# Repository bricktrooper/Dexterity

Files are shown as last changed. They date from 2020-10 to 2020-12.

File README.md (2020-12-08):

# Dexterity

Dexterity is a wearable gesture recognition device which uses custom hardware, firmware, and software to measure hand movement and finger position via an array of specialized sensors.  This data can be interpreted in real time to identify hand gestures and execute corresponding actions on a computer system.  Dexterity is designed to be a scalable and can be used as a peripheral for any electronic device.  This makes it suitable for a variety of applications involving gesture recognition.

A common approach towards gesture recognition is to use computer vision and machine learning in order to decipher gestures through a video feed.  This can be a computationally intensive task, depending on the complexity of the algorithms and the hardware capabilities, which in turn increases latency and decreases throughput.

Dexterity tackles this issue by placing sensors directly on a wearable glove.  The sensors are continuously sampled by an onboard microcontroller, which transmits the readings to a host PC via a high-speed serial UART connection.  The stronger hardware of the host can then be used to run interpretation algorithms on the raw readings.  This avoids placing unnecessary computational stress on a low power device while providing a more accurate model of the hand compared to computer vision.

## Hardware

Dexterity's hardware consists of a glove equipped with 8 sensors and a microcontroller.  Each finger has an attached flex sensor, which changes resistance when the finger bends.  This allows the position of each finger to be read accurately.  Additionally, a 3-axis analogue accelerometer is placed on the top of the glove, which can be used to determine the movement and orientation of the hand.

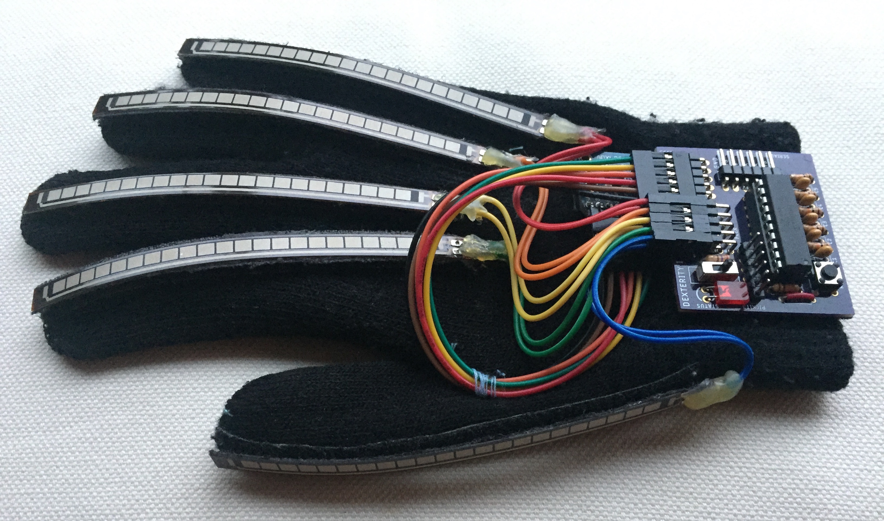
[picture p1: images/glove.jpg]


The device is powered by a custom circuit board with a Microchip PIC16F690 microcontroller.  This is an 8-bit low power computer that reads the flex sensors and accelerometer using its analogue-to-digital converter (ADC).

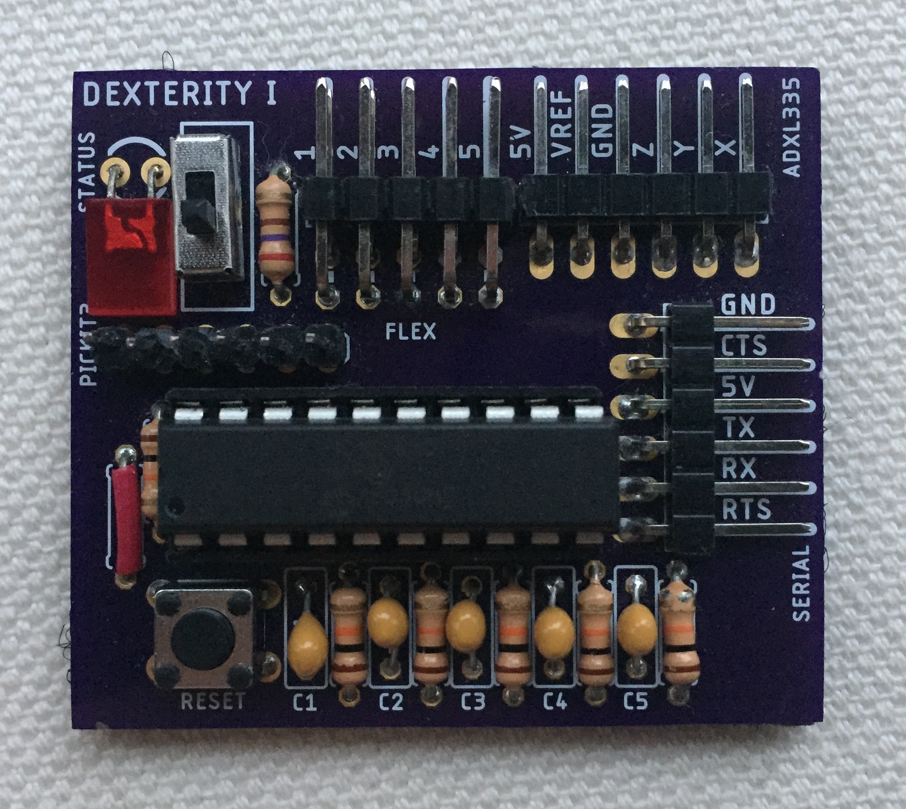
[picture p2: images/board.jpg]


The board requires a wired serial connection, which doubles as the 5V power supply.  If a wireless serial transmitter is used in the future, then a separate battery will be needed to power the board.  The accelerometer is an ADXL335 3-axis sensor module, composed of analogue output pins for the X, Y, and Z spatial directions.  Resistors were added for the flex sensors to produce a voltage divider sampling node, and 0.1uF filtering capacitors were added for noise reduction.  The board also contains an enable/disable button and a status LED.  Typical current draw ranges between 3.5mA and 4mA with a 5V supply.

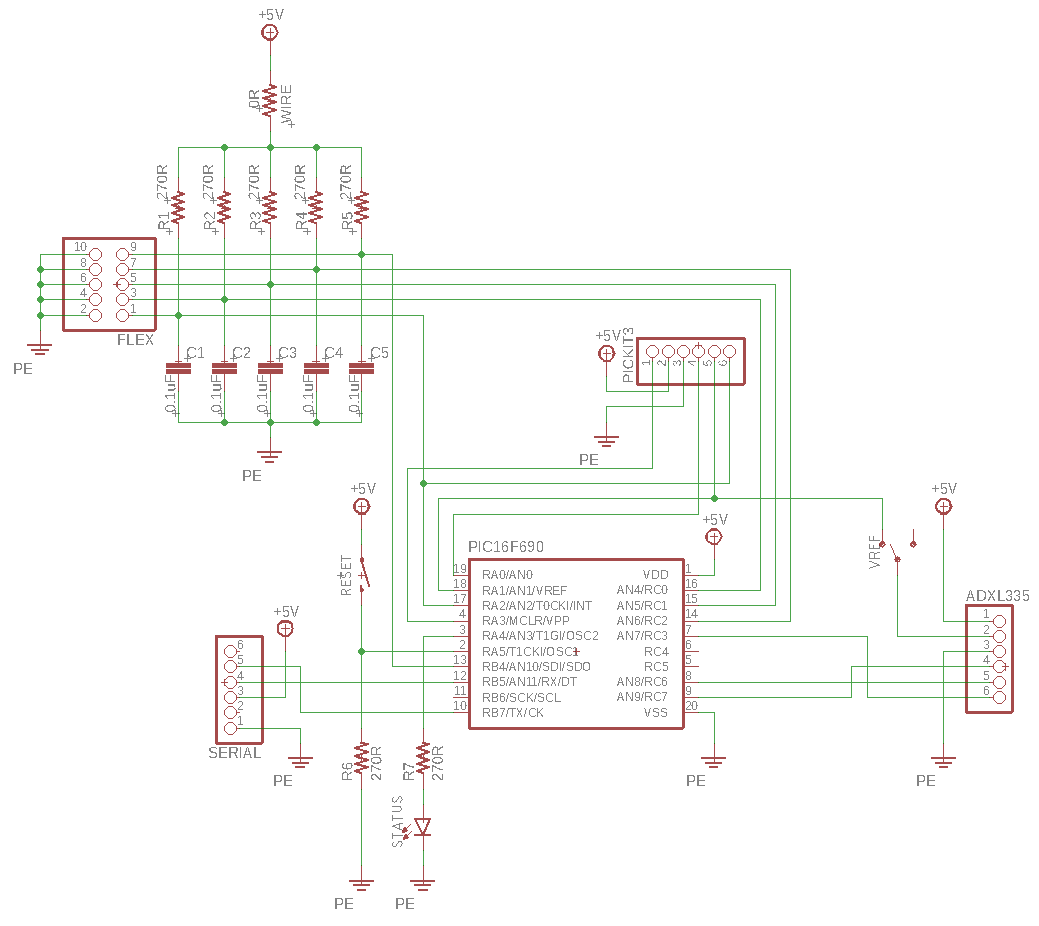
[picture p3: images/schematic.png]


Autodesk EAGLE was used to complete schematic entry and board layout.  These files can be found under the `hardware` directory.

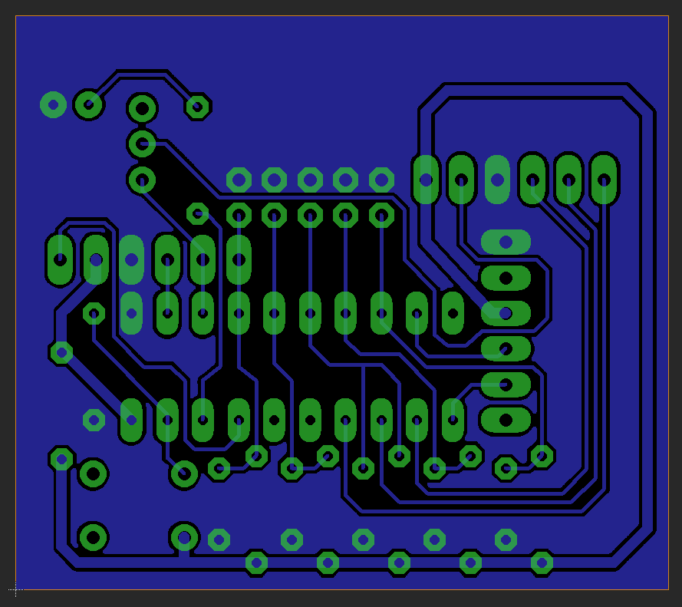
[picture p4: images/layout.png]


## Firmware

Custom firmware was developed to run on the PIC microcontroller.  This program runs forever as long as the board is powered.  The source code is located in the `firmware` directory.

The firmware reads the analogue voltages of each of the 8 sensors.  Each sensor is attached to an input pin, and the PIC will perform an ADC conversion on each of these analogue voltage inputs.  The microcontroller can also scale the readings between a certain range, which is useful for gesture interpretation.  If this is disabled, then the raw 10-bit ADC conversion values are returned instead.

The PIC transmits readings to a host device over a serial UART running at a baud rate of 115200 bits per second.  This results in less than 1ms of latency for data retrieval from the device.  The clock frequency of the PIC was increased to a maximum of 8MHz, which further reduces latency and increases the computational power.

The PIC can also send the current calibration settings to the host.  Similarly, the host can upload new calibration settings to the PIC.  Additionally, the host can tell the device to enable or disable scaling of the sensor readings.

The host and the device communicate using a set of short string messages.  The host will send messages to the PIC, and the firmware will continuously poll for a message.  If a valid message is received, the PIC will perform the requested action and return an ACK message signalling a success or an error.  In some cases, a data payload is sent instead of an ACK, such as a set of sensor readings.

## Software

The software is responsible for communicating with the device and interpreting the sensor readings to execute a specific function on the host computer.  The source code is located in the `software` directory of the repository.

The device must be connected to the computer via a serial-to-USB cable.  It is important that this cable is a **5V** variant and not a 3.3V variant, as a 5V supply is needed to power the device hardware.  The cable must have an embedded **FTDI FT232RL** chip, which allows the serial UART to appear as a USB device.  FTDI drivers may need to be installed to have this cable function correctly.

The software opens a serial port file descriptor and sets the attributes to match the settings used by the PIC.  The user can issue a variety of commands via the `dexterity` command line utility that the software compiles to.  While the main software is running, the program will continuously request sensor readings from the PIC.  Once the data arrives, it will be fed to an interpretation algorithm, which attempts to identify a hand gesture based on the average error and the tolerance.

If the readings match one of the valid gestures from the gesture list, then a corresponding action will be performed on the computer.  This might include playing/pausing a song, or moving and clicking the mouse.  There are different control modes as well, each with a different set of gestures.  The modes can be cycled through by flicking the thumb down and up again while keeping the other fingers straight and relaxed.  Pressing the push button on the board at any point will suspend the program.  The program can be resumed by pressing the button again.

The program will require a calibration file and a gestures file in order to function.  These can be found under the `config` directory, and can be easily modified for the application.

**NOTE:** The current software only works on Mac OS X, since it makes use of Apple's Quartz Event Services API.  This allows the program to inject events into HID stream in order to emulate mouse and keyboard events.  The software only supports the device as a computer peripheral, but the generality of the design can allow the user to control any electromechanical function by binding the trigger software appropriately.

## Compilation Instructions

### Build System

Dexterity uses a Makefile build system that compiles each source file separately and links the object files together at the end to produce a program binary.  The build system uses the `gcc` compiler to automatically generate file dependencies based on included header files.  These dependencies are stored in `*.d` dependency files.  The Makefiles use generalized pattern rules, which makes them highly scalable.  This allows additional source files to be added without major modifications to the Makefile.  All artifacts of the build system are placed in `bin` directories under the `software` and `firmware` source code folders.

### Firmware

The firmware is written in a dialect of C that is specific to the PIC microcontroller. The source code must be compiled using Microchip's XC8 compiler toolchain.  You will need to have these tools installed in order to build the firmware.  To compile the code, navigate to the `firmware` directory of the repository and execute the Makefile by typing `make`.  This will compile the code using the `xc8-cc` compiler and linker.  Each source file is compiled separately into object files with the `*.p1` extension, which are then linked into a single `*.hex` binary file and stored in the `bin` folder.  If you would like to view the PIC memory usage statistics, then add `MEMORY=show` as an argument when running `make`.  The firmware also has an alternate test program, which runs simple tests for each part of the firmware.  You can compile this version using the `test` target and by adding `TYPE=<TEST_NAME>`, where `TEST_NAME` can be any of the following:
* `INIT_TEST`
* `UART_TEST`
* `ADC_TEST`
* `ACCEL_TEST`
* `FLEX_TEST`
* `LED_TEST`
* `BUTTON_TEST`

To compile the test program:
```
make test TYPE=<TEST_NAME>
```
The test program can only be compiled from within the `firmware` directory.

### Software

The software is implemented in C with a few special functions written in Objective-C
The source code must be compiled using the Apple's version of the LLVM Clang compiler, which is able to link to the frameworks required for emulating the mouse and keyboard on Mac OS X.  Note that this will require installation of Apple's XCode command line tools, which include Clang and the Apple frameworks.  To compile the code, navigate to the `software` directory of the repository and execute the Makefile by typing `make`.  This will compile the code using the `clang` compiler and linker.  Each source file is compiled separately into object files with the `*.o` extension, which are then linked into an executable binary file and stored in the `bin` folder.  This `dexterity` binary file is executable from the command line.

### Top Level Build

Both the software and the firmware can be compiled at the same time by executing `make` from the top-level directory.  The top level Makefile will invoke the Makefiles from the `software` and `firmware` directories and place all generated artifacts in their respective `bin` folders, while also copying the binaries to a top level `artifacts` folder.

## Loading the Firmware

**IMPORTANT:** Before loading the firmware, slide the switch on the circuit board **away from the PIC** and **towards the edge of the board**.  This will disconnect the VREF input pin from the 3.3V pin on the ADXL335, putting the line in a high impedance state and eliminating any signalling conflicts.  Failing to do this will prevent the PICKit3 from interfacing with the PIC.

The firmware should be loaded onto the device using a PICKit3 serial in-circuit programmer.  Microchip's MPLAB IPE is required to connect to the PIC and load the `*.hex` firmware binary.

## Running the Program

**IMPORTANT:** Before running the program, ensure that the slide switch on the circuit board is moved **towards the PIC** and **away from the edge of the board**.  This attaches the VREF input of the PIC to the 3.3V pin on the ADXL335.  Failing to do this will result in the device producing an incorrect ADC reading for the acceleration axes.

The `dexterity` binary produced by compiling the software is an executable file.  You can run this from the command line:
```
./dexterity
```

This should bring up a list of available subcommands.  If you would like to use this command from anywhere, add the location of the binary to your PATH variable.

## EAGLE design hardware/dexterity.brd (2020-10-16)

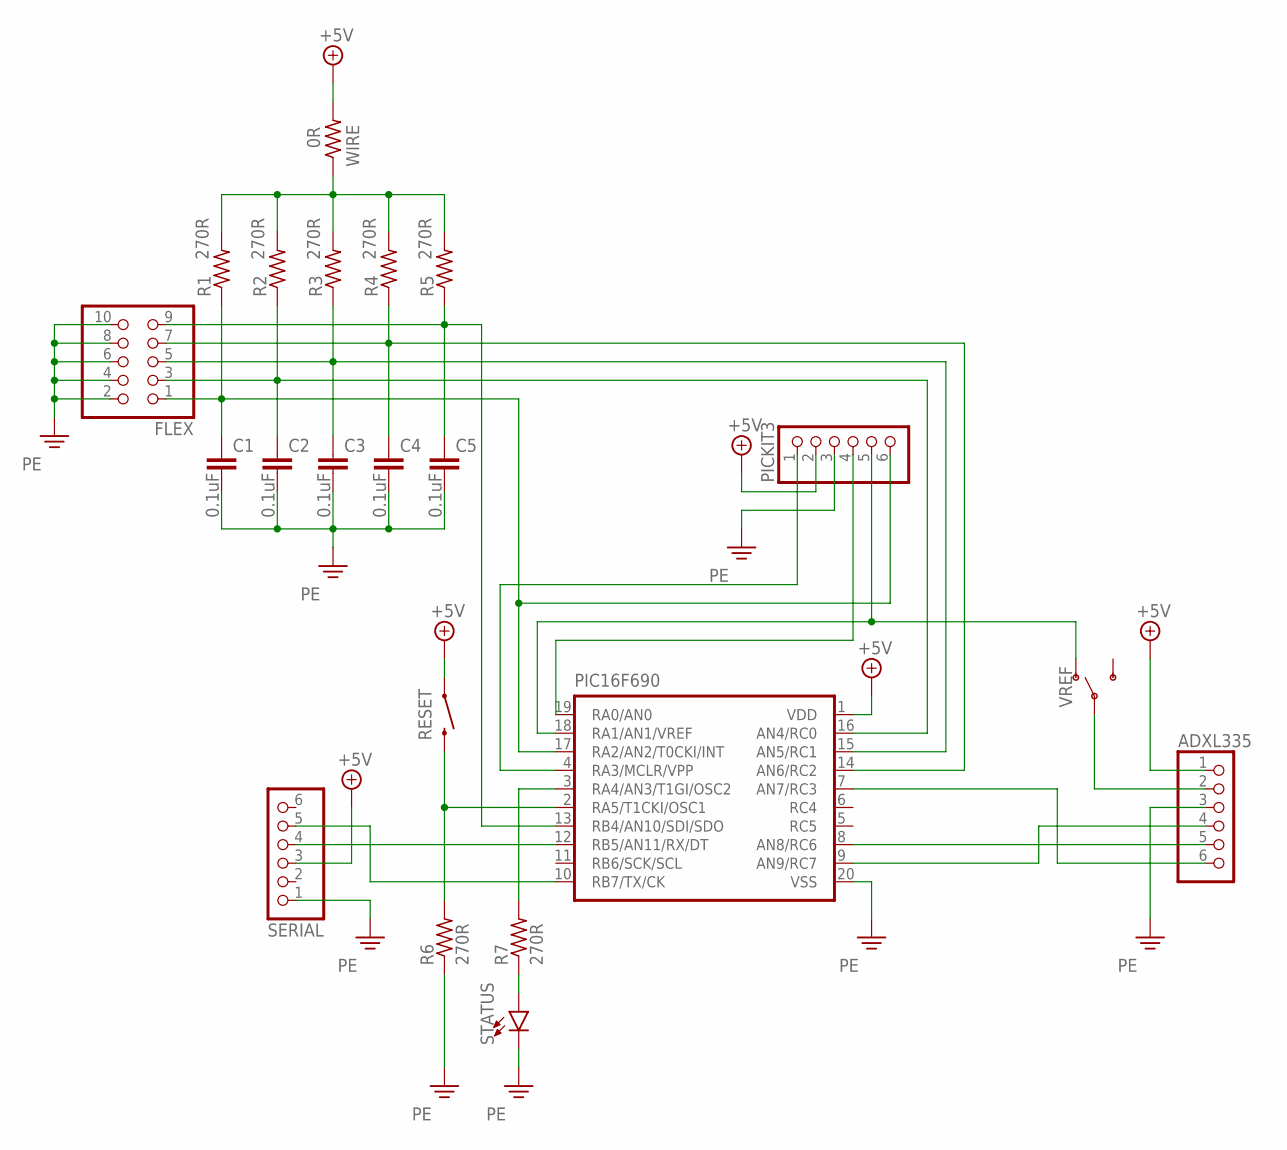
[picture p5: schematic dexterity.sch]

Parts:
ADXL335: PINHD-1X6/90; 1X06/90
C1, C2, C3, C4, C5: 0.1uF; C050-025X075
FLEX: PINHD-2X5/90; 2X05/90
PIC16F690: PIC16F6XX; DIL20
PICKIT3: PINHD-1X6; 1X06
R1, R2, R3, R4, R5, R6, R7: 270R; 0207/7
RESET: MOMENTARY-SWITCH-SPST-PTH-6.0MM; TACTILE_SWITCH_PTH_6.0MM
SERIAL: PINHD-1X6/90; 1X06/90
STATUS: LED3MM; LED_3MM
VREF: SWITCH-SPDT-PTH-11.6X4.0MM; SWITCH_SPDT_PTH_11.6X4.0MM
WIRE: 0R; 0207/7

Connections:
+5V: ADXL335.1, PIC16F690.1 (VDD), PICKIT3.2, R1.2, R2.2, R3.2, R4.2, R5.2, RESET.1, SERIAL.3, WIRE.1, WIRE.2
GND: ADXL335.3, C1.2, C2.2, C3.2, C4.2, C5.2, FLEX.2, FLEX.4, FLEX.6, FLEX.8, FLEX.10, PIC16F690.20 (VSS), PICKIT3.3, R6.1, SERIAL.1, STATUS.K (C)
unnamed: ADXL335.2, VREF.2
unnamed: PIC16F690.18 (RA1/AN1/VREF), PICKIT3.5, VREF.1 (O)
unnamed: PIC16F690.12 (RB5/AN11/RX/DT), SERIAL.4
unnamed: PIC16F690.10 (RB7/TX/CK), SERIAL.5
unnamed: PIC16F690.3 (RA4/AN3/T1GI/OSC2), R7.2
unnamed: ADXL335.5, PIC16F690.8 (AN8/RC6)
unnamed: ADXL335.6, PIC16F690.7 (AN7/RC3)
unnamed: PIC16F690.4 (RA3/MCLR/VPP), PICKIT3.1
unnamed: C2.1, FLEX.3, PIC16F690.16 (AN4/RC0), R2.1
unnamed: PIC16F690.19 (RA0/AN0), PICKIT3.4
unnamed: C1.1, FLEX.1, PIC16F690.17 (RA2/AN2/T0CKI/INT), PICKIT3.6, R1.1
unnamed: C3.1, FLEX.5, PIC16F690.15 (AN5/RC1), R3.1
unnamed: C4.1, FLEX.7, PIC16F690.14 (AN6/RC2), R4.1
unnamed: C5.1, FLEX.9, PIC16F690.13 (RB4/AN10/SDI/SDO), R5.1
unnamed: ADXL335.4, PIC16F690.9 (AN9/RC7)
unnamed: R7.1, STATUS.A
unnamed: PIC16F690.2 (RA5/T1CKI/OSC1), R6.2, RESET.3 (2)

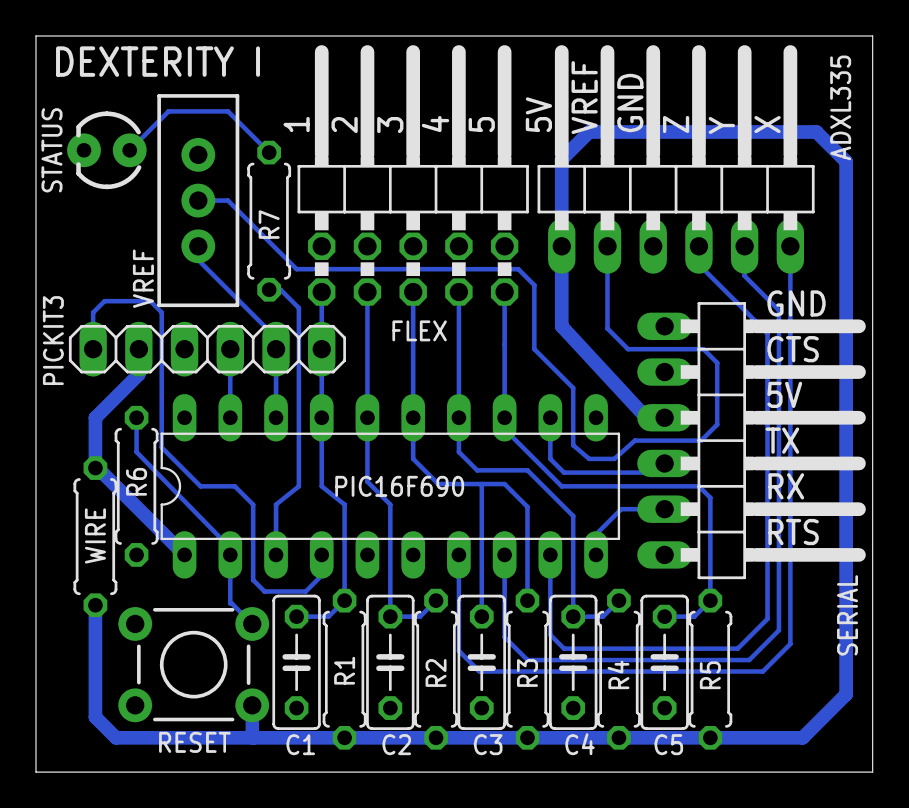
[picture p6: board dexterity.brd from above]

Board: 2 copper layers, 46.5 x 40.9 mm, 21 parts (0 on the bottom side), 19 nets.

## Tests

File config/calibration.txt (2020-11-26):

accel-range=100
flex-range=2
X      MIN=528 MAX=600 CENTRE=50
Y      MIN=487 MAX=603 CENTRE=0
Z      MIN=406 MAX=614 CENTRE=50
THUMB  MIN=560 MAX=726 CENTRE=0
INDEX  MIN=548 MAX=780 CENTRE=0
MIDDLE MIN=531 MAX=750 CENTRE=0
RING   MIN=524 MAX=763 CENTRE=0
PINKY  MIN=530 MAX=724 CENTRE=0

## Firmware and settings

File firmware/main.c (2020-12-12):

#include <xc.h>
#include <pic16f690.h>

#include <string.h>
#include <stdbool.h>

#include "dexterity.h"
#include "pins.h"
#include "utils.h"
#include "init.h"
#include "led.h"
#include "button.h"
#include "uart.h"
#include "adc.h"
#include "accel.h"
#include "flex.h"

void init(void);
int sample(Hand * hand);
void raw(void);
void scaled(void);
int calibrate(Calibration * calibration);
int settings(Calibration * calibration);

void main(void)
{
	init();
	led_off();

	Hand hand;
	Calibration calibration;
	Message message;

	while (1)
	{
		// operations that change the device state will require an ACK
		// operations that simply request data do not require a separate ACK
		message = uart_receive_message();

		switch (message)
		{
			case MESSAGE_SAMPLE:   // read the analogue sensors and transmit the results

				sample(&hand);
				uart_transmit(&hand, sizeof(Hand));
				break;

			case MESSAGE_RAW:   // use raw ADC readings

				raw();
				uart_transmit_message(MESSAGE_SUCCESS);
				break;

			case MESSAGE_SCALED:   // scale ADC readings using the calibration

				scaled();
				uart_transmit_message(MESSAGE_SUCCESS);
				break;

			case MESSAGE_UPLOAD:   // receive the calibration settings and apply them

				uart_transmit_message(MESSAGE_SUCCESS);   // handshake with the host

				if (uart_receive(&calibration, sizeof(Calibration)) != sizeof(Calibration))
				{
					uart_transmit_message(MESSAGE_ERROR);
					break;
				}

				calibrate(&calibration);                  // apply the calibration
				uart_transmit_message(MESSAGE_SUCCESS);   // send an ACK when finished
				break;

			case MESSAGE_DOWNLOAD:   // transmit the current calibration settings

				settings(&calibration);                             // copy the current calibration settings
				uart_transmit(&calibration, sizeof(Calibration));   // send the calibration back to the host
				break;

			case MESSAGE_UNKNOWN:   // respond with error if an unexpected or unknown message is received
			default:

				uart_transmit_message(MESSAGE_ERROR);
				break;
		}
	}
}

void init(void)
{
	init_hardware();
	led_init();
	button_init();
	uart_init();
	adc_init();
	accel_init();
	flex_init();
}

int sample(Hand * hand)
{
	if (hand == NULL)
	{
		return ERROR;
	}

	// ACCELEROMETER //

	adc_vref(VREF_EXTERNAL);

	hand->accel[X] = accel_read(X);
	hand->accel[Y] = accel_read(Y);
	hand->accel[Z] = accel_read(Z);

	// FLEX SENSORS //

	adc_vref(VREF_INTERNAL);

	hand->flex[THUMB] = flex_read(THUMB);
	hand->flex[INDEX] = flex_read(INDEX);
	hand->flex[MIDDLE] = flex_read(MIDDLE);
	hand->flex[RING] = flex_read(RING);
	hand->flex[PINKY] = flex_read(PINKY);

	// BUTTON STATE //

	hand->button = BUTTON;

	// LED STATE //

	hand->led = LED;

	return SUCCESS;
}

void raw(void)
{
	accel_mode(RAW);
	flex_mode(RAW);
}

void scaled(void)
{
	accel_mode(SCALED);
	flex_mode(SCALED);
}


int calibrate(Calibration * calibration)
{
	if (calibration == NULL)
	{
		return ERROR;
	}

	if (accel_calibrate(&calibration->accel) == ERROR ||
		flex_calibrate(&calibration->flex) == ERROR)
	{
		return ERROR;
	}

	return SUCCESS;
}

int settings(Calibration * calibration)
{
	if (calibration == NULL)
	{
		return ERROR;
	}

	if (accel_settings(&calibration->accel) == ERROR ||
		flex_settings(&calibration->flex) == ERROR)
	{
		return ERROR;
	}

	return SUCCESS;
}

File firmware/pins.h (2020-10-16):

#ifndef PINS_H
#define PINS_H

// STATUS LED //

#define LED        RA4
#define LED_TRIS   TRISA4

// RESET BUTTON //

#define BUTTON        RA5
#define BUTTON_TRIS   TRISA5

// ACCELEROMETER //

#define X_TRIS   TRISC3
#define Y_TRIS   TRISC6
#define Z_TRIS   TRISC7

#define X_ANSEL   ANS7
#define Y_ANSEL   ANS8
#define Z_ANSEL   ANS9

#define X_CHANNEL   7
#define Y_CHANNEL   8
#define Z_CHANNEL   9

// FLEX SENSORS //

#define F1_TRIS    TRISA2
#define F2_TRIS    TRISC0
#define F3_TRIS    TRISC1
#define F4_TRIS    TRISC2
#define F5_TRIS    TRISB4

#define F1_ANSEL   ANS2
#define F2_ANSEL   ANS4
#define F3_ANSEL   ANS5
#define F4_ANSEL   ANS6
#define F5_ANSEL   ANS10

#define F1_CHANNEL   2
#define F2_CHANNEL   4
#define F3_CHANNEL   5
#define F4_CHANNEL   6
#define F5_CHANNEL   10

#endif /* PINS_H */

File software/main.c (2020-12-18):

#include <stdio.h>
#include <stdlib.h>
#include <libgen.h>

#include "dexterity.h"
#include "log.h"
#include "utils.h"
#include "command.h"

#define ARGV_MIN          1   // no subcommand
#define ARGV_MAX          4   // subcommand + arguments
#define ARGV_PROGRAM      0
#define ARGV_SUBCOMMAND   1
#define ARGV_ARGUMENTS    2

int main(int argc, char ** argv)
{
	// LOGGING SETTINGS //

	log_suppress(LOG_ERROR, false);
	log_suppress(LOG_WARNING, false);
	log_suppress(LOG_SUCCESS, false);
	log_suppress(LOG_INFO, false);
	log_suppress(LOG_DEBUG, true);

	log_trace(false);   // don't print the source of log messages

	// PARSE ARGUMENTS //

	if (argc < ARGV_MIN)
	{
		log(LOG_ERROR, "Insufficient arguments\n");
		print_usage(COMMAND_DEXTERITY, false);
		return ERROR;
	}

	if (argc > ARGV_MAX)
	{
		log(LOG_ERROR, "Too many arguments\n");
		print_usage(COMMAND_DEXTERITY, false);
		return ERROR;
	}

	if (argv == NULL)
	{
		log(LOG_ERROR, "Invalid argument vector\n");
		return ERROR;
	}

	char * subcommand = NULL;
	char ** arguments = NULL;
	int count = 0;

	if (argc > 1)
	{
		subcommand = argv[ARGV_SUBCOMMAND];
	}

	if (argc > 2)
	{
		count = argc - 2;
		arguments = &argv[ARGV_ARGUMENTS];
	}

	// RUN DEXTERITY //

	return dexterity(subcommand, arguments, count);
}

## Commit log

2020-09-21 firmware: Add basic init code for PIC16F690
    Basic initialization code for
    PIC operation. Configures the
    following features of the device:
    - Digital I/O
    - Analogue I/O
    - Internal Oscillator 4MHz (~3.6864MHz)
    - Initialization of GPIO PORTs
    A startup indication will be shown
    on PORTC is if the PIC test board is
    being used.
    [init.c]
2020-09-21 firmware: Create test file to run init code
    test.c will run the basic init code
    on the PIC. If the PIC test board
    is being used, the PORTC LEDs will
    light up.
2020-10-16 build: Add Makefile and guards for test board code
    Create a Makefile for building an init test
    program. If the PIC test board setting is
    used, the PORTC LEDs will flash and the
    buttons (RA4 and RA5) will be set as inputs.
    Also added init/out directory to .gitignore
2020-10-16 firmware: Add basic init code for testing
    This is later replaced by the init module
    [init.c]
2020-10-16 firmware: Add Makefile and test code file
    test.c will be used to test the UART code.
2020-10-16 firmware: Implement UART send function to output data serially
    This can be used to output to a console that
    operates at the same baud rate (9600).
2020-10-16 firmware: Implement UART receive functionality
    The PIC will read bytes until a null
    terminator, newline, or carriage return
    is received. It will then append a null
    terminator to the recieved data.
2020-10-16 firmware: Add error checking to UART functions
    [uart.c]
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2020-10-16 firmware: Remove init code from UART
    The init.c code is just a generic
    setup for the PIC and will appear
    instead in a seperate init folder.
    This allows multiple modules to
    access the init code in their
    individual test programs.
2020-10-16 firmware: ignore UART out folder
    The out directory just holds
    the build artifacts and does
    not need to be tracked.
2020-10-16 build: Update Makefile to use init module
    the UART test.c should use the init module
    instead of the old local init code.
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2020-10-16 firmware: Add buffer size to TX function
    Specify the size of the data buffer
    that is to be transmitted on the TX
    line. This is safer and more secure
    then transmitting until a newline or
    null terminator, which will be handled
    in the serial module's print functions.
2020-10-16 firmware: Create UART print functions
    Created printing functions for debugging
    and system console logging. These were
    implemented using the built-in putch()
    association, which adapts printf() to
    output to the UART instead of stdout.
    Functions currently available:
    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
2020-10-16 firmware: Add test code for Serial O/I
    Currently only tests printing over UART.
2020-10-16 firmware: Implement serial read function
    Add function to read input from UART
    into a buffer.
2020-10-16 firmware: Fix TRISB comment
    RB4 was marked as N/C.
    [init.c]
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2020-10-16 firmware: Implement ADC module functionality
    Added the following functions for operation
    of the ADC module:
    - adc_init()
    - adc_run()
    - adc_set_channel()
    - adc_read()
2020-10-16 firmware: Create test program for ADC
    Tests ADC readings from RB4 (AN10)
    and prints out the reading using
    functions from the serial module.
2020-10-16 firmware: Tune internal oscillator for new PICs
    When transistioning to breadboard development
    a brand new PIC16F690 was used. In order for
    the UART to correctly function, the internal
    oscillator needs to be tuned down to its
    minimum frequency. However, the UART on the
    original test board PIC functions correctly
    at the factory-calibrated default tuning level.
    Create preprocessor wrappings to deal with
    this difference. The cause of this may be
    investigated later, however the final product
    will use the new chips.
    [init.c, uart.c]
2020-10-16 firmware: Add LED status indicator on RC5
    This functions like the PORTC startup
    indicator from the PIC test board.
2020-10-16 hardware: Create first version of PCB
    Board was designed in EAGLE based on a schematic of the breadboard
    layout. The board will have the following features:
    - status LED
    - flex sensor angled DIP
    - accelerometer angled SIP
    - UART serial angled SIP
    - PICKit3 programmer SIP
    - PIC16F690 microcontroller
    - reset button with pull down resistor
    - slide switch for setting VREF to high-Z (used when programming PIC)
    - flex sensor pull up resistors
    - flex sensor filtering capacitors
    [dexterity.brd, dexterity.sch]
2020-10-16 firmware: Define min and max ADC readings
    Minimum ADC reading = 0
    Maximum ADC reading = 1023
2020-10-16 firmware: Read ADXL335 values using ADC
    The values will be scaled so that maximum acceleration is +100 and
    minimum acceleration is -100. Since the ADXL335 uses 3.3V as reference,
    the VREF for the ADC will be set to the 3.3V external line. This must
    be manually set before reading accelerometer readings.
2020-10-16 firmware: Read flex sensors using ADC
    The flex sensor values were scaled to the 0 <-> 100 range.
    This should be further calibrated when the flex sensors are on the
    glove. The addition of filtering capacitors will also change the
    calibration settings.
    [flex.c]
2020-10-16 firmware: Move all PIC code to firmware folder
    This will keep the repo more organized given that there will be
    different code for the drivers and user application.
2020-10-16 hardware: Rename EAGLE folder to 'pcb'
    This folder now has a special .gitignore to ignore backups for
    schematics and layouts that are automatically generated by EAGLE.
    [dexterity.brd, dexterity.sch]
2020-10-16 build: Add rule for building test firmware
    The regular firmware can be built using 'make dexterity' or simply
    'make'. This will compile the firmware using dexterity.c as the main
    program. To build the test firmware using test.c as the main program,
    run 'make test TYPE=<test_type>', where 'test_type' is the defined macro
    in test.c that specifies which test function to run.
    This eliminates the need to edit the source code of test.c in order to
    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
2020-10-16 firmware: Create pins.h containing pinout constants
    This file is used to store macros that are aliased with the pin names
    and analogue channels for the various peripherals on the board. This
    includes the accelerometer, flex sensors, LED, and button.
    [accel.c, flex.c, init.c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]
2020-10-16 firmware: Update test.c to work with Dexterity I board
    Updated the LED pins to work with init_test().
    Also removed the hardcoded macro at the top to work with the new build
    system that allows specification of the test type from the command line.
2020-10-16 hardware: Rename 'pcb' folder to 'hardware'
    [dexterity.brd, dexterity.sch]
2020-10-16 firmware: Added code for controlling status LED
    This new module allows the user to turn the LED on or off, as well as
    link the LED at a certain speed. This LED will be useful as a visual
    indicator of activity on the board.
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2020-10-16 firmware: Improve scaling and remove floating point operations
    Doing floating point operations on the PIC is much slower than integer
    operations and it takes up too much program space. The scaling has been
    optimized to use only integer arithmetic.
    Also added enums for organizing accelerometer and flex sensor settings
    and data.
    [accel.c, flex.c, test.c]
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2020-10-16 firmware: Fix pin assignments
    [pins.h]
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2020-10-16 software: Develop serial I/O module
    This code will be used to manage the UNIX serial port.
    It is capable of reading and writing data to and from the device.
    Note that the transmission has delays inserted between each byte,
    which avoids overrunning the PIC's RX buffer.
2020-10-16 firmware: Check for RX buffer overrun
    If data comes in too fast it will overrun the RX buffer
    and lock the receiver. Check for this while looping in
    uart_receive() and reset the receiver if necessary.
    [uart.c]
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2020-10-16 common: Use standard size for transmitted data fields
    On the PIC an int is a 16b number, while on the host it
    is usually a 32b number. These sizes must be consistent
    in order to avoid data misinterpretation.
    Use the int16_t type to represent all integer data that
    will be transmitted and received over UART between the
    device and the host.
    [accel.c, adc.c, dexterity.h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]
2020-10-16 common: Move enums for accel and flex into universal header
    [dexterity.h]
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2020-10-16 common: Move common source code files into a central folder
    The Makefile include paths had to be tweaked to accommodate this.
    Also added a single file for messages, which avoids having multiple
    definitions in different files. All files will link to this one.
    [dexterity.h, test.c]
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2020-10-16 common: Add strings for accel and flex in common
    This is just for printing aesthetics.
    [dexterity.h]
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2020-10-16 common: Fix size of shared data structures and enums
    The sizeof operator was not being used correctly.
    Use macro constants instead and enforce these sizes
    on the string arrays in dexterity.c
    [dexterity.h]
2020-10-16 common: Fix analogue parameter ordering
    Make it consistent with the PIC code ordering
    [dexterity.h]
2020-10-16 software: Add interactive calibration
    This allows the user to calibrate the analogue sensor limits
    using the push button. These values can be sent to the device
    to correct the output scaling.
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2020-10-16 firmware: Transmit current calibration upon request
    The device will transfer its current calibration values
    when the host requests them via the correct message.
    [main.c]
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2020-10-16 build: Prevent Makefile from regenerating dependencies during a clean
    We don't need to generate dependencies when running 'make clean'
    [adc.c]
2020-10-16 build: Fix dependency generation to track headers
    The header files were not being tracked by make
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2020-10-16 common: Put enum lengths inside enumeration list
    The number of enumerations for each type of enum were originally defined
    as macros. This may have been causing warnings, especially if enum
    numbering is different between gcc and xc8. By making the last enum
    member the length of the enum, we can always ensure that the correct
    length is used across the firmware and the software.
    [dexterity.h]
2020-10-16 build: Fix individual target recipes
    The artifacts should be copied to the top level even when individual
    recipes are run. Also fixed the printing to work with the -j option.
2020-10-17 common: Remove error code from scaling function
    This function returns the scaled value. We cannot return an error code
    as the scaled value may be the same as the error code. If there is an
    error, simply return the sensor reading unchanged.
2020-10-17 firmware: Implement retrieval of calibration settings
    Added a new function for flex and accel that will fetch the current
    calibration settings so that they can be send back to the host PC.
    [accel.c, flex.c, main.c]
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2020-10-17 software: Remove debug print in sampling function
    This is unnecessary overhead, even if suppressed.
    This function must have minimal latency, so this
    printing can be done manually elsewhere. The sample
    subcommand will replace this functionality anyway.
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2020-10-24 firmware: Increase PIC internal oscillator frequency to 8MHz
    This effectively doubles the device operation speed from the original
    4MHz frequency, resulting in faster computation and sampling of sensors.
    This will also result in increased thermals for the chip.
    [init.c]
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2020-10-24 software: Prevent cursor from moving beyond the screen limits
    Quartz already prevents this but the mouse coordinates can still become
    invalid. Currently this uses the hardcoded limits of a 1920x1080 screen
    but these should be set dynamically at runtime.
2020-10-27 software: Check explicitly for error code in function return codes
    [main.c]
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2020-10-28 common: Use void pointers for passing buffers
    This avoids ugly casting when calling the function.
    casts to char pointer handles are done withing the
    functions themselves.
    [main.c, uart.c]
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2020-10-28 software: Purge serial port before every write
    serial_purge() was inserted directly into serial_write().
    This avoids the need to manually call it before every write.
    The logic behind purging is to clear an pending data that may be
    stuck in the TX buffer. This ensures that the new data is transmitted
    as expected without any additional remnants from previous transfers.
    The RX buffer is never purged before data is read from the serial port,
    as read() may block, so we don't want to lose data if the entire
    transmission is still coming in. write() will simply dump the data in
    the TX buffer and return, so we don't know for sure when it has been
    transmitted. This is the reason we use serial_purg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
2020-10-29 software: Fix byte counter print for serial error message
2020-10-31 common: Restructure calibration struct to use 2D array
    This allows us to iterate over the analogue calibration parameters
    easily, similar to how the acceleration and flex sensor readings can
    be iterated over using their enums.
    [dexterity.h]
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2020-10-31 firmware: ACK with error if an unexpected or unknown message is received
    [main.c]
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2020-11-02 software: Fix calibration export success message
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2020-11-02 software: Fix segfault in phase label mismatch printing
2020-11-02 common: Fix indentation for broken lines
    Tabs should only be used for indenting different scopes and levels of
    code. For formatting code beyond this point use spaces to ensure that
    the code lines up correctly.
    [accel.c, flex.c]
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2020-11-08 software: Use a separate phase for each gesture
    This avoid confusion when switching between different gestures.
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2020-12-02 software: Control volume using gestures
    Volume is a separate mode of operation. If all the hand fingers are
    clasped, then the volume can be controlled by tiling left and right.
    Also improved the gesture for overview so that it does not get mistaken
    with a recovery from a drag gesture.
    [dexterity.h]
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2020-12-03 software: Re-download calibration after uploading to verify data
    There is the possibility that noise could corrupt either the upload or
    the download, but it seems to be rare. In any case, if there is a
    suspicion on data corruption during an upload, the user will be notified.
2020-12-03 common: Change WARNING return code from 1 to -2
    A UNIX signals might have a value of 1 and this should not be confused
    with an return code of WARNING. All three return codes (ERROR, SUCCESS,
    and WARNING) will be <= 0 to avoid conflicting with UNIX signal values
    which are > 0 (these signals may interrupt the program via end()).
    [dexterity.h, main.c]
2020-12-04 common: Shorten max message
    The size was much larger than the possible max size.
    [dexterity.h]
2020-12-05 software: Create help and usage messages
    These can be triggered using the '--help' command line argument.
    Each subcommand has its own help message which shows the user how
    to use that subcommand and what it does. Using '--help' on the
    root command will bring up a menu of all the supported commands.
    NOTE: the 'mode' subcommand was reverted back to the 'raw' and
    'scaled' subcommands for implementation simplicity.
    [main.c]
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2020-12-12 software: Overwrite control printing
    This prevents the program from continuously
    dumping output to the terminal.
    [dexterity.h]
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

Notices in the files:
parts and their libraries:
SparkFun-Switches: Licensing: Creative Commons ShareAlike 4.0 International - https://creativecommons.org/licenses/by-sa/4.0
